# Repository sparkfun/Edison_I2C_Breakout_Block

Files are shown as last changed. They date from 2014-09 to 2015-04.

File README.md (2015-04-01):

SparkFun Edison I2C Breakout Block
==================================

SparkFun Edison I2C Breakout Block

[*SparkFun Edison I2C Breakout Block(DEV-13034)*](https://www.sparkfun.com/products/13034)

This I2C Block simply breaks out an I2C bus on the Intel® Edison while level shifting it from 1.8V to your sensors voltage. This a simple board that can snap into your Edison and be used right away.

Repository Contents
-------------------
* **Hardware** - All Eagle diesgn files (.brd, .sch)
* **/Production** - Test bed files and production panel files

License Information
-------------------
The hardware is released under [Creative Commons ShareAlike 4.0 International](https://creativecommons.org/licenses/by-sa/4.0/).
The code is beerware; if you see me (or any other SparkFun employee) at the local, and you've found our code helpful, please buy us a round!

Distributed as-is; no warranty is given.

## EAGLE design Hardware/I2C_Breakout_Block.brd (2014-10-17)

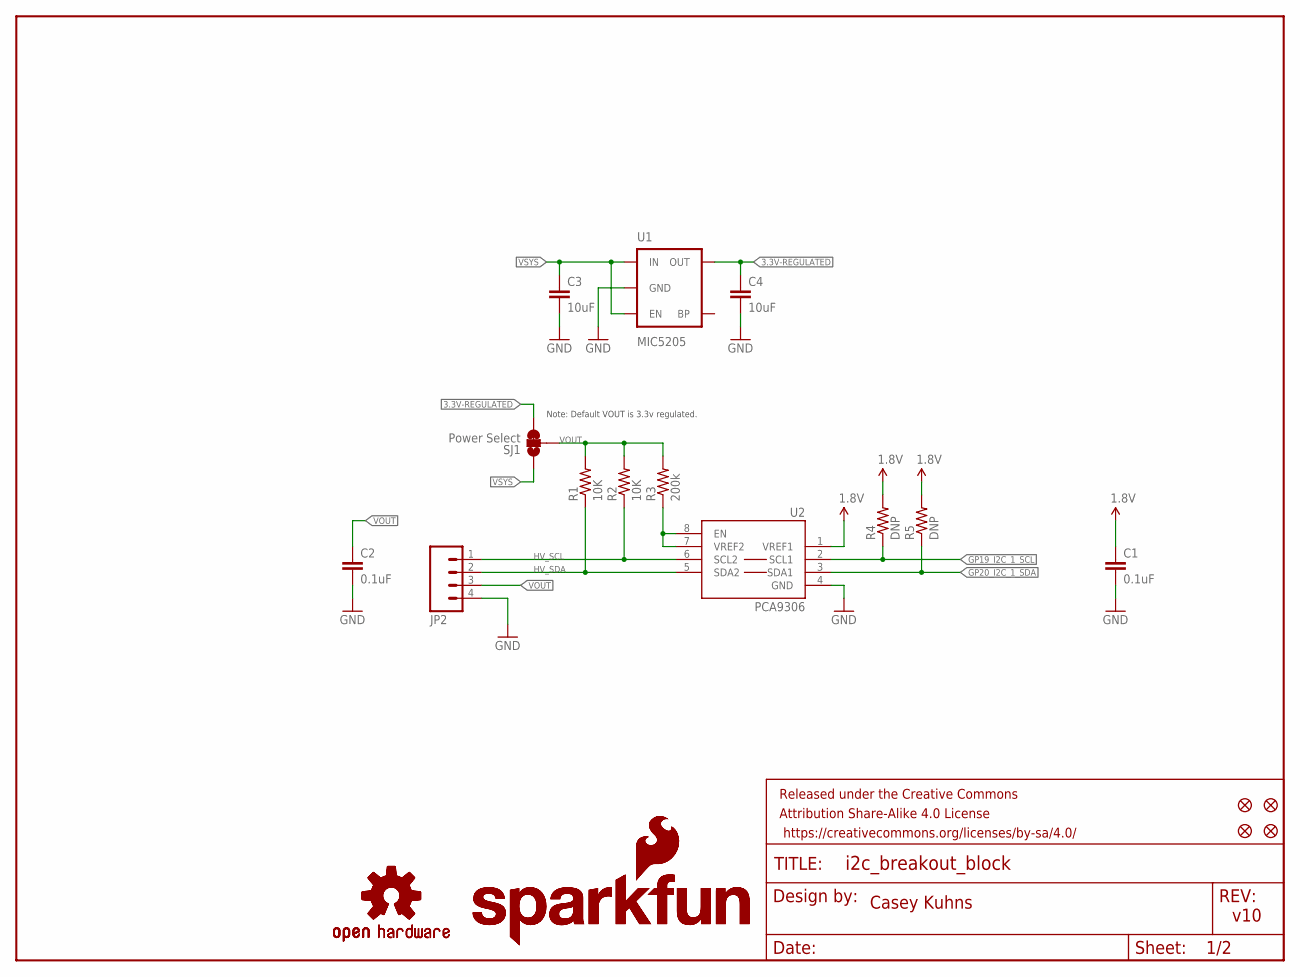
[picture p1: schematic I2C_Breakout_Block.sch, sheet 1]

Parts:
C1, C2: 0.1uF; 0603-CAP
C3, C4: 10uF; 1206
FID1, FID2, FID3, FID4: FIDUCIAL1X2; FIDUCIAL-1X2
FRAME1: FRAME-LETTER; CREATIVE_COMMONS
JP2: M04SMD_RA_FEMALE; 1X04_SMD_RA_FEMALE
LOGO1, LOGO3: SFE_LOGO_NAME_FLAME.1_INCH; SFE_LOGO_NAME_FLAME_.1
LOGO2, LOGO4: OSHW-LOGOS; OSHW-LOGO-S
R1, R2: 10K; 0603-RES
R3: 200k; 0603-RES
R4, R5: DNP; 0603-RES
SJ1: Power Select; PAD-JUMPER-3-2OF3_NC_BY_TRACE_YES_SILK_FULL_BOX
U1: MIC5205; SOT23-5
U2: PCA9306; PCA9306DC-1:1

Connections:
1.8V: C1.1, R4.2, R5.2, U2.1 (VREF1); also elsewhere on the board
3.3V-REGULATED: C4.1, SJ1.3, U1.5 (OUT)
GND: C1.2, C2.2, C3.2, C4.2, JP2.4, U1.2 (GND), U2.4 (GND); also elsewhere on the board
GP19_I2C_1_SCL: R4.1, U2.2 (SCL1); also elsewhere on the board
GP20_I2C_1_SDA: R5.1, U2.3 (SDA1); also elsewhere on the board
HV_SCL: JP2.1, R2.1, U2.6 (SCL2)
HV_SDA: JP2.2, R1.1, U2.5 (SDA2)
unnamed: R3.1, U2.7 (VREF2), U2.8 (EN)
VOUT: C2.1, JP2.3, R1.2, R2.2, R3.2, SJ1.2
VSYS: C3.1, SJ1.1, U1.1 (IN), U1.3 (EN); also elsewhere on the board

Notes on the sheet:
Casey Kuhns
v10
Note: Default VOUT is 3.3v regulated.

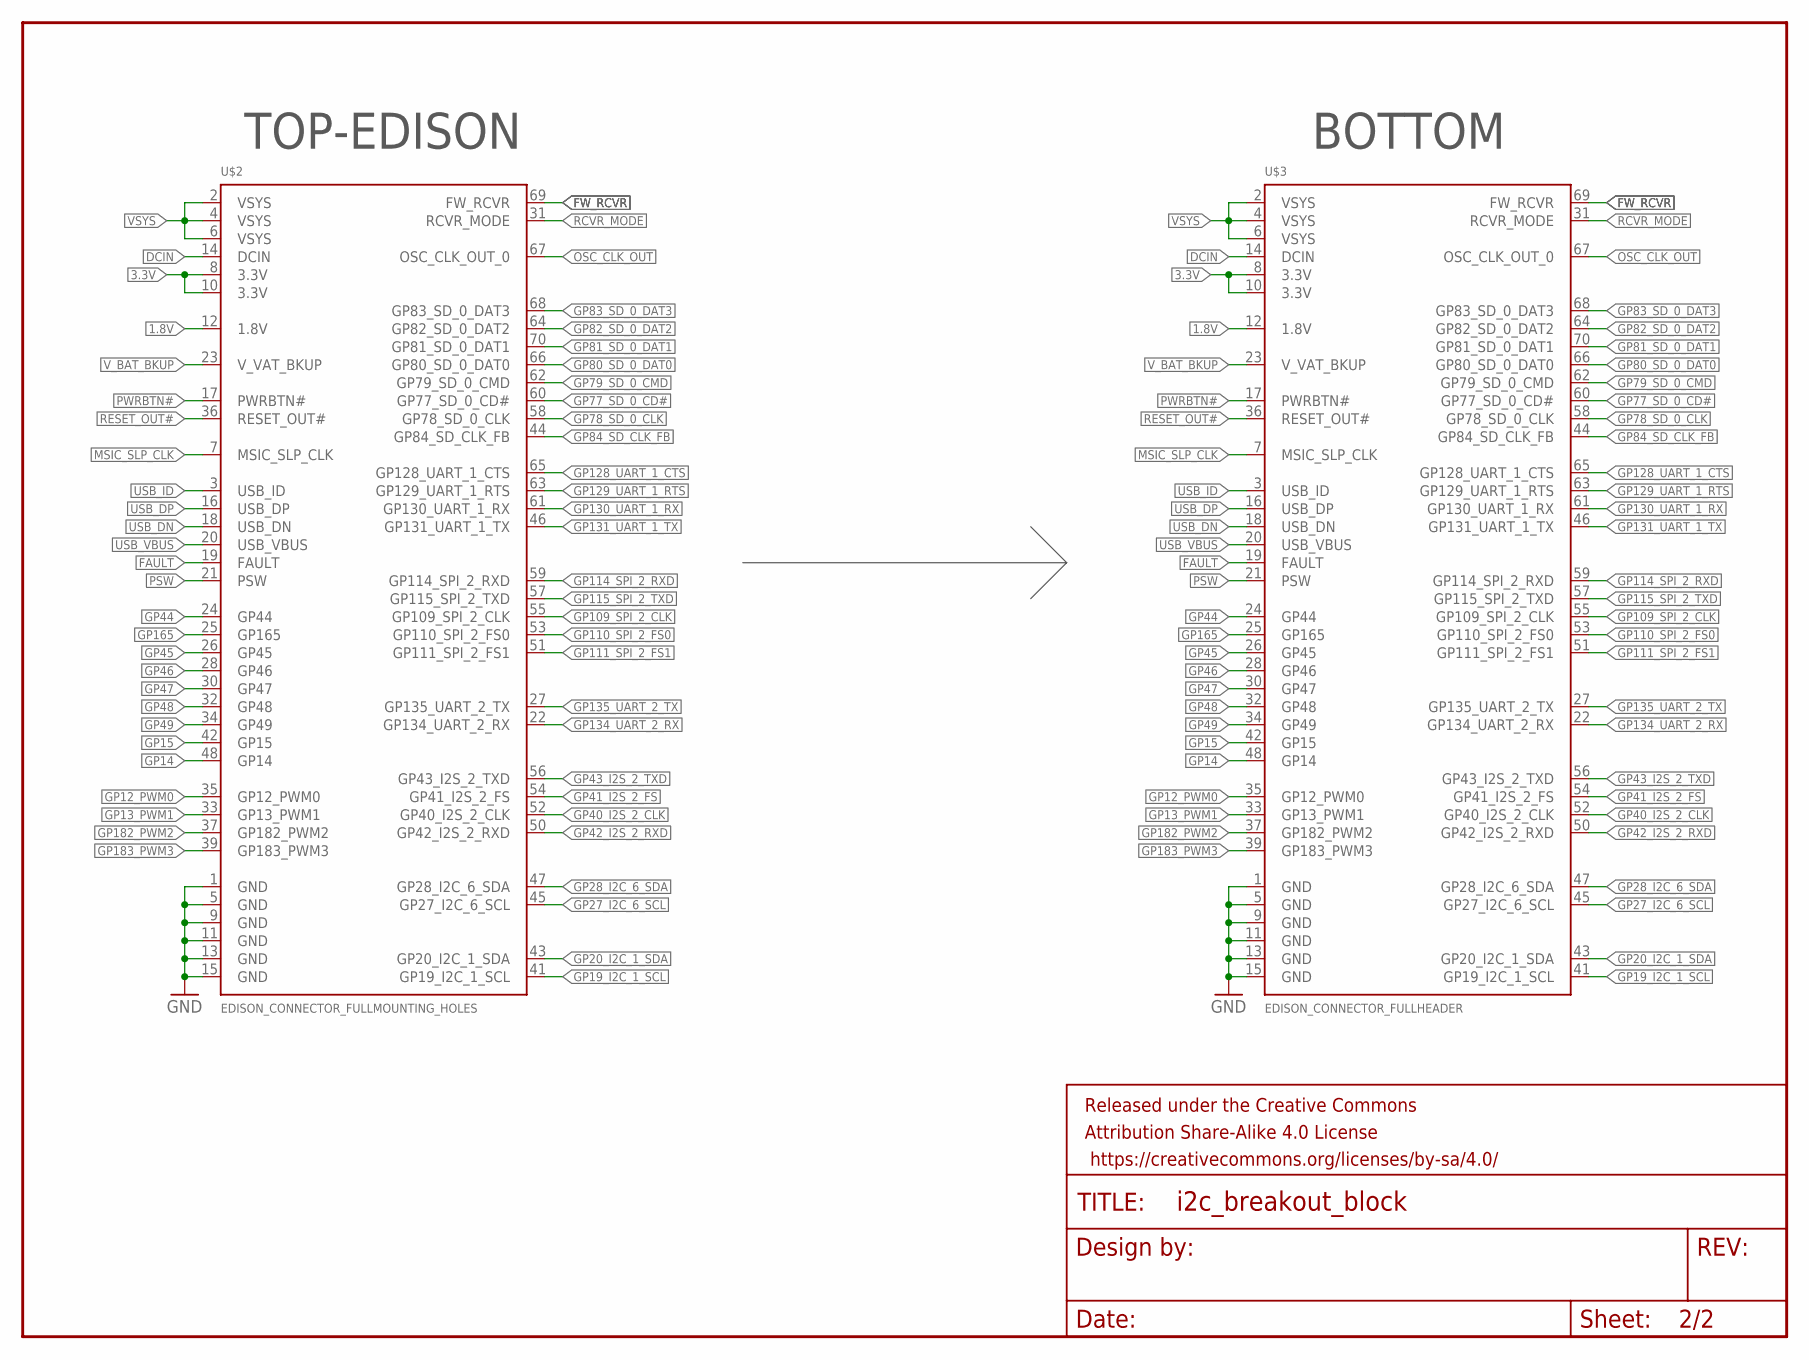
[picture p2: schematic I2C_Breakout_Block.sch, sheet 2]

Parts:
FRAME2: FRAME-LETTER; CREATIVE_COMMONS
U$2: EDISON_CONNECTOR_FULLMOUNTING_HOLES; EDISON_DAUGHTER
U$3: EDISON_CONNECTOR_FULLHEADER; DF40C-70DP-0.4(51)

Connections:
1.8V: U$2.12 (1.8V), U$3.12 (1.8V); also elsewhere on the board
3.3V: U$2.8 (3.3V), U$2.10 (3.3V), U$3.8 (3.3V), U$3.10 (3.3V)
DCIN: U$2.14 (DCIN), U$3.14 (DCIN)
FAULT: U$2.19 (FAULT), U$3.19 (FAULT)
FW_RCVR: U$2.69 (FW_RCVR), U$3.69 (FW_RCVR)
GND: U$2.1 (GND), U$2.5 (GND), U$2.9 (GND), U$2.11 (GND), U$2.13 (GND), U$2.15 (GND), U$3.1 (GND), U$3.5 (GND), U$3.9 (GND), U$3.11 (GND), U$3.13 (GND), U$3.15 (GND); also elsewhere on the board
GP12_PWM0: U$2.35 (GP12_PWM0), U$3.35 (GP12_PWM0)
GP13_PWM1: U$2.33 (GP13_PWM1), U$3.33 (GP13_PWM1)
GP14: U$2.48 (GP14), U$3.48 (GP14)
GP15: U$2.42 (GP15), U$3.42 (GP15)
GP19_I2C_1_SCL: U$2.41 (GP19_I2C_1_SCL), U$3.41 (GP19_I2C_1_SCL); also elsewhere on the board
GP20_I2C_1_SDA: U$2.43 (GP20_I2C_1_SDA), U$3.43 (GP20_I2C_1_SDA); also elsewhere on the board
GP27_I2C_6_SCL: U$2.45 (GP27_I2C_6_SCL), U$3.45 (GP27_I2C_6_SCL)
GP28_I2C_6_SDA: U$2.47 (GP28_I2C_6_SDA), U$3.47 (GP28_I2C_6_SDA)
GP40_I2S_2_CLK: U$2.52 (GP40_I2S_2_CLK), U$3.52 (GP40_I2S_2_CLK)
GP41_I2S_2_FS: U$2.54 (GP41_I2S_2_FS), U$3.54 (GP41_I2S_2_FS)
GP42_I2S_2_RXD: U$2.50 (GP42_I2S_2_RXD), U$3.50 (GP42_I2S_2_RXD)
GP43_I2S_2_TXD: U$2.56 (GP43_I2S_2_TXD), U$3.56 (GP43_I2S_2_TXD)
GP44: U$2.24 (GP44), U$3.24 (GP44)
GP45: U$2.26 (GP45), U$3.26 (GP45)
GP46: U$2.28 (GP46), U$3.28 (GP46)
GP47: U$2.30 (GP47), U$3.30 (GP47)
GP48: U$2.32 (GP48), U$3.32 (GP48)
GP49: U$2.34 (GP49), U$3.34 (GP49)
GP77_SD_0_CD#: U$2.60 (GP77_SD_0_CD#), U$3.60 (GP77_SD_0_CD#)
GP78_SD_0_CLK: U$2.58 (GP78_SD_0_CLK), U$3.58 (GP78_SD_0_CLK)
GP79_SD_0_CMD: U$2.62 (GP79_SD_0_CMD), U$3.62 (GP79_SD_0_CMD)
GP80_SD_0_DAT0: U$2.66 (GP80_SD_0_DAT0), U$3.66 (GP80_SD_0_DAT0)
GP81_SD_0_DAT1: U$2.70 (GP81_SD_0_DAT1), U$3.70 (GP81_SD_0_DAT1)
GP82_SD_0_DAT2: U$2.64 (GP82_SD_0_DAT2), U$3.64 (GP82_SD_0_DAT2)
GP83_SD_0_DAT3: U$2.68 (GP83_SD_0_DAT3), U$3.68 (GP83_SD_0_DAT3)
GP84_SD_CLK_FB: U$2.44 (GP84_SD_CLK_FB), U$3.44 (GP84_SD_CLK_FB)
GP109_SPI_2_CLK: U$2.55 (GP109_SPI_2_CLK), U$3.55 (GP109_SPI_2_CLK)
GP110_SPI_2_FS0: U$2.53 (GP110_SPI_2_FS0), U$3.53 (GP110_SPI_2_FS0)
GP111_SPI_2_FS1: U$2.51 (GP111_SPI_2_FS1), U$3.51 (GP111_SPI_2_FS1)
GP114_SPI_2_RXD: U$2.59 (GP114_SPI_2_RXD), U$3.59 (GP114_SPI_2_RXD)
GP115_SPI_2_TXD: U$2.57 (GP115_SPI_2_TXD), U$3.57 (GP115_SPI_2_TXD)
GP128_UART_1_CTS: U$2.65 (GP128_UART_1_CTS), U$3.65 (GP128_UART_1_CTS)
GP129_UART_1_RTS: U$2.63 (GP129_UART_1_RTS), U$3.63 (GP129_UART_1_RTS)
GP130_UART_1_RX: U$2.61 (GP130_UART_1_RX), U$3.61 (GP130_UART_1_RX)
GP131_UART_1_TX: U$2.46 (GP131_UART_1_TX), U$3.46 (GP131_UART_1_TX)
GP134_UART_2_RX: U$2.22 (GP134_UART_2_RX), U$3.22 (GP134_UART_2_RX)
GP135_UART_2_TX: U$2.27 (GP135_UART_2_TX), U$3.27 (GP135_UART_2_TX)
GP165: U$2.25 (GP165), U$3.25 (GP165)
GP182_PWM2: U$2.37 (GP182_PWM2), U$3.37 (GP182_PWM2)
GP183_PWM3: U$2.39 (GP183_PWM3), U$3.39 (GP183_PWM3)
MSIC_SLP_CLK: U$2.7 (MSIC_SLP_CLK), U$3.7 (MSIC_SLP_CLK)
OSC_CLK_OUT: U$2.67 (OSC_CLK_OUT_0), U$3.67 (OSC_CLK_OUT_0)
PSW: U$2.21 (PSW), U$3.21 (PSW)
PWRBTN#: U$2.17 (PWRBTN#), U$3.17 (PWRBTN#)
RCVR_MODE: U$2.31 (RCVR_MODE), U$3.31 (RCVR_MODE)
RESET_OUT#: U$2.36 (RESET_OUT#), U$3.36 (RESET_OUT#)
USB_DN: U$2.18 (USB_DN), U$3.18 (USB_DN)
USB_DP: U$2.16 (USB_DP), U$3.16 (USB_DP)
USB_ID: U$2.3 (USB_ID), U$3.3 (USB_ID)
USB_VBUS: U$2.20 (USB_VBUS), U$3.20 (USB_VBUS)
VSYS: U$2.2 (VSYS), U$2.4 (VSYS), U$2.6 (VSYS), U$3.2 (VSYS), U$3.4 (VSYS), U$3.6 (VSYS); also elsewhere on the board
V_BAT_BKUP: U$2.23 (V_VAT_BKUP), U$3.23 (V_VAT_BKUP)

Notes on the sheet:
TOP-EDISON
BOTTOM

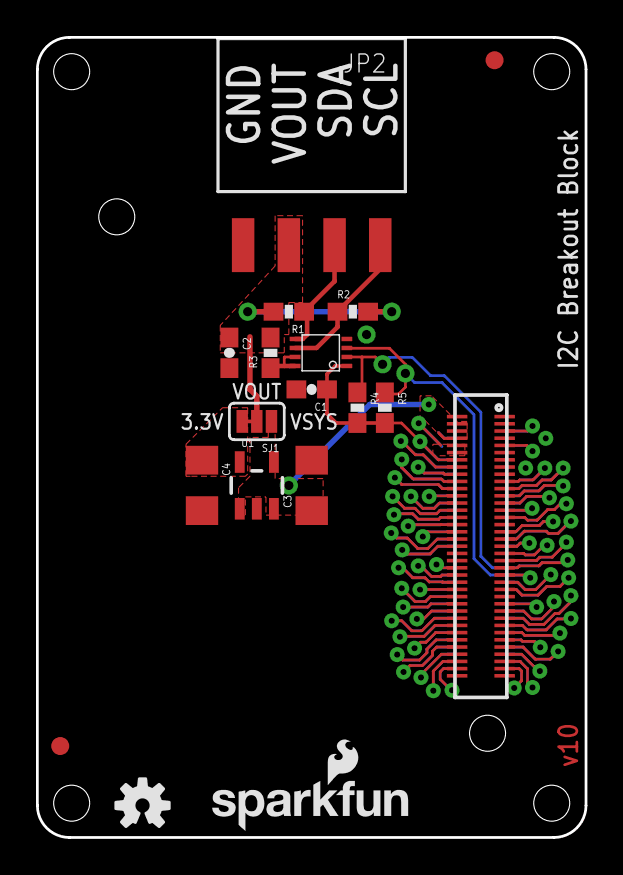
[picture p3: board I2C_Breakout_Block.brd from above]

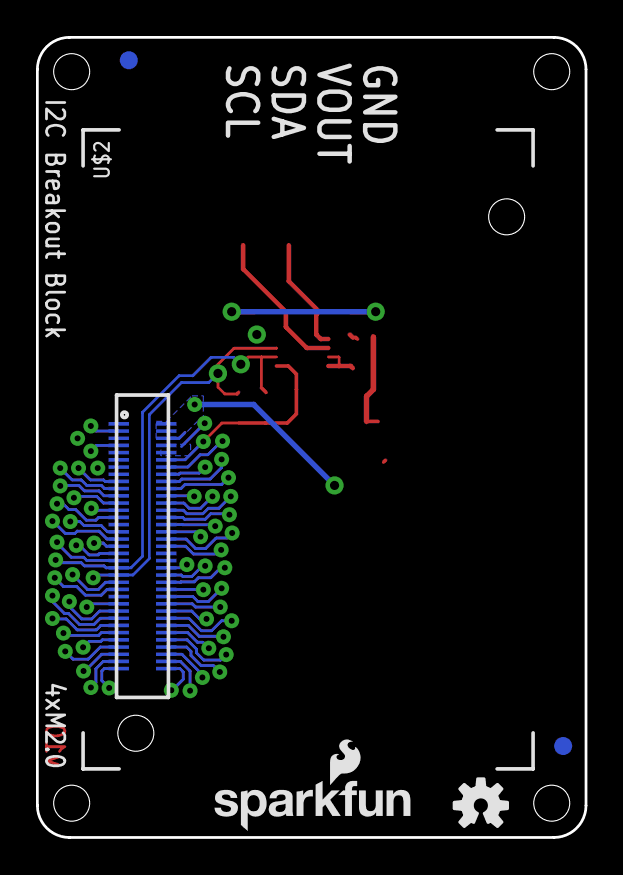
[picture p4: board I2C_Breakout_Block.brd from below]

Board: 2 copper layers, 30.5 x 44.5 mm, 25 parts (6 on the bottom side), 63 nets.

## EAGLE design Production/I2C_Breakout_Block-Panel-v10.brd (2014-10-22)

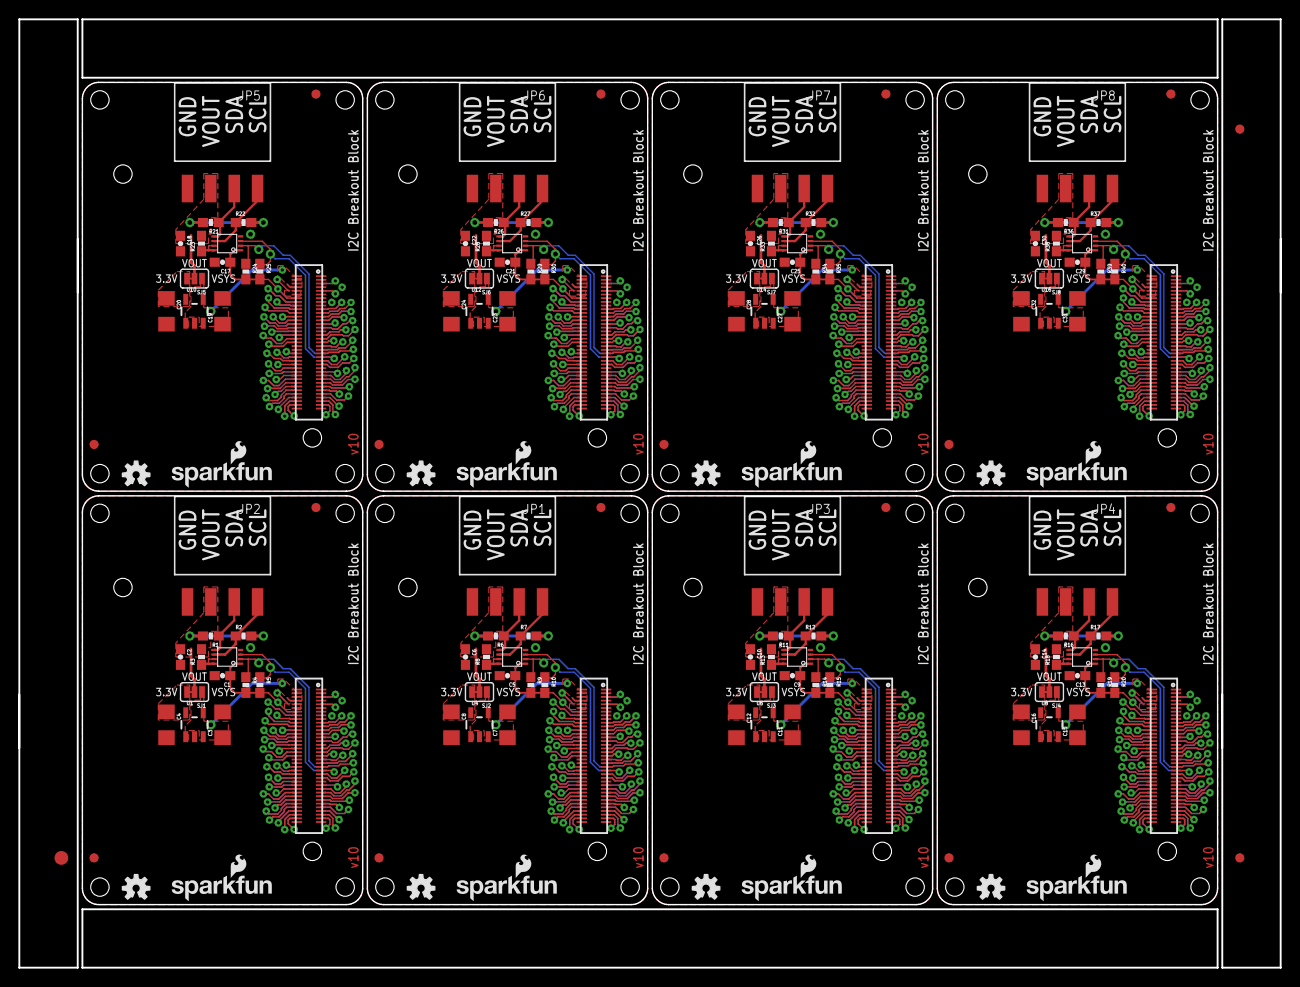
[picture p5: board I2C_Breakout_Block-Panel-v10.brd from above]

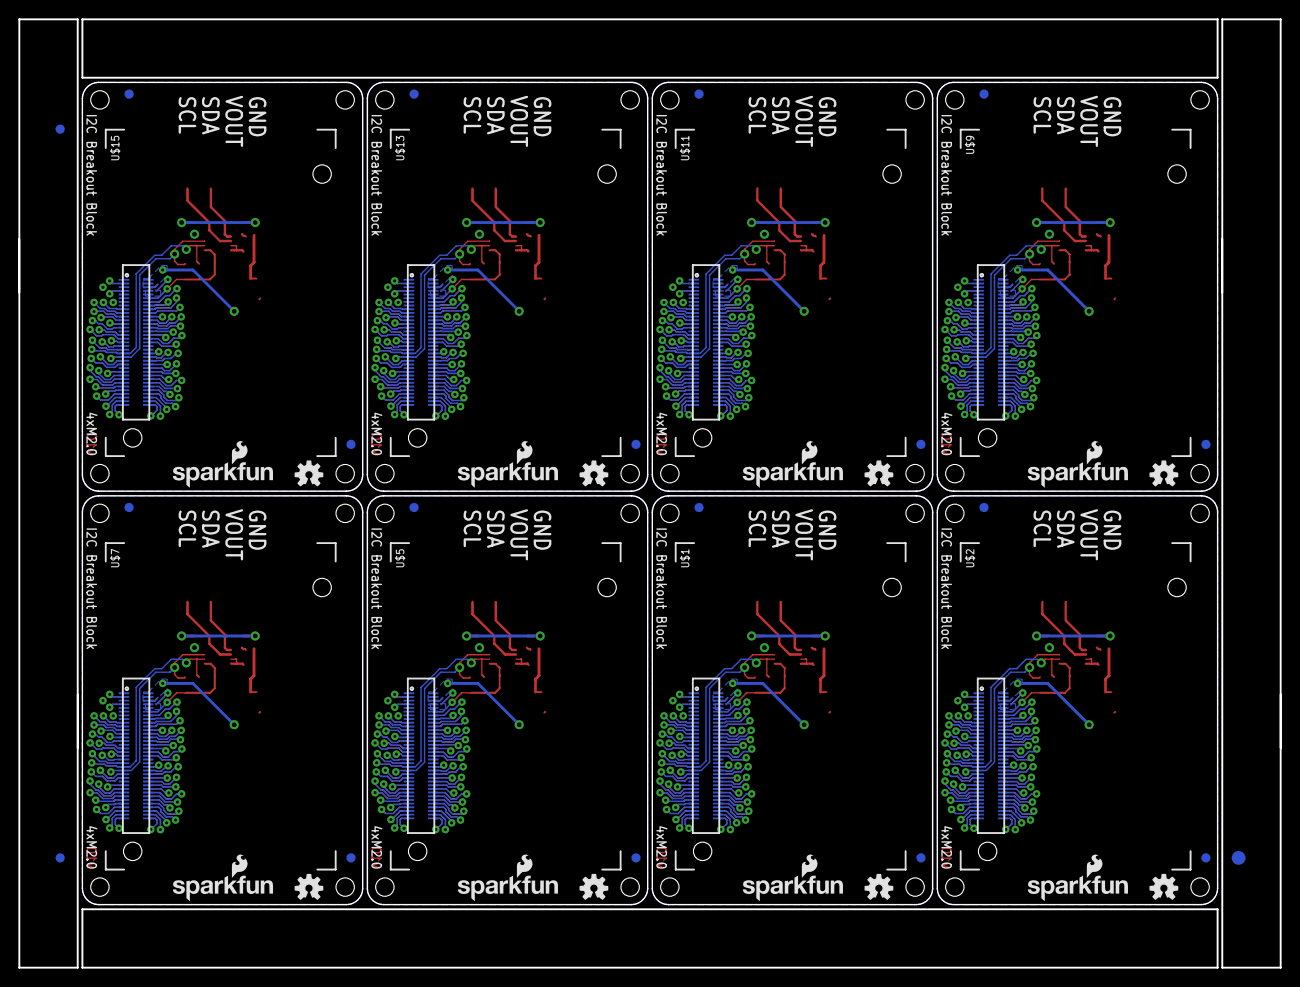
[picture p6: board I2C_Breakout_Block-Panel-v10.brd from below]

Board: 2 copper layers, 137.2 x 103.1 mm, 190 parts (51 on the bottom side), 504 nets.

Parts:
C1, C2, C5, C6, C9, C10, C13, C14, C17, C18, C21, C22, C25, C26, C29, C30: 0.1uF; 0603-CAP
C3, C4, C7, C8, C11, C12, C15, C16, C19, C20, C23, C24, C27, C28, C31, C32: 10uF; 1206
E$1, E$2: FIDUCIAL-1.5X3
E$3, E$4, E$5, E$6: FIDUCIAL-1X2
FID1, FID2, FID3, FID4, FID5, FID6, FID7, FID8, FID9, FID10, FID11, FID12, FID13, FID14, FID15, FID16, FID17, FID18, FID19, FID20, FID21, FID22, FID23, FID24, FID25, FID26, FID27, FID28, FID29, FID30, FID31, FID32: FIDUCIAL1X2; FIDUCIAL-1X2
JP1, JP2, JP3, JP4, JP5, JP6, JP7, JP8: 1X04_SMD_RA_FEMALE
LOGO1, LOGO3, LOGO6, LOGO7, LOGO10, LOGO11, LOGO14, LOGO15, LOGO18, LOGO19, LOGO22, LOGO23, LOGO26, LOGO27, LOGO30, LOGO31: SFE_LOGO_NAME_FLAME.1_INCH; SFE_LOGO_NAME_FLAME_.1
LOGO2, LOGO4, LOGO5, LOGO8, LOGO9, LOGO12, LOGO13, LOGO16, LOGO17, LOGO20, LOGO21, LOGO24, LOGO25, LOGO28, LOGO29, LOGO32: OSHW-LOGOS; OSHW-LOGO-S
R1, R2, R6, R7, R11, R12, R16, R17, R21, R22, R26, R27, R31, R32, R36, R37: 10K; 0603-RES
R3, R8, R13, R18, R23, R28, R33, R38: 200k; 0603-RES
R4, R5, R9, R10, R14, R15, R19, R20, R24, R25, R29, R30, R34, R35, R39, R40: DNP; 0603-RES
SJ1, SJ2, SJ3, SJ4, SJ5, SJ6, SJ7, SJ8: Power Select; PAD-JUMPER-3-2OF3_NC_BY_TRACE_YES_SILK_FULL_BOX
U1, U4, U6, U8, U10, U12, U14, U16: MIC5205; SOT23-5
U2, U3, U5, U7, U9, U11, U13, U15: PCA9306; PCA9306DC-1:1
U$1, U$2, U$5, U$7, U$9, U$11, U$13, U$15: EDISON_CONNECTOR_FULLMOUNTING_HOLES; EDISON_DAUGHTER
U$3, U$4, U$6, U$8, U$10, U$12, U$14, U$16: EDISON_CONNECTOR_FULLHEADER; DF40C-70DP-0.4(51)

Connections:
1.8V: C1.1, R4.2, R5.2, U2.1, U$2.12, U$3.12
1.8V1: C5.1, R9.2, R10.2, U3.1, U$1.12, U$4.12
1.8V2: C9.1, R14.2, R15.2, U5.1, U$5.12, U$6.12
1.8V3: C13.1, R19.2, R20.2, U7.1, U$7.12, U$8.12
1.8V4: C17.1, R24.2, R25.2, U9.1, U$9.12, U$10.12
1.8V5: C21.1, R29.2, R30.2, U11.1, U$11.12, U$12.12
1.8V6: C25.1, R34.2, R35.2, U13.1, U$13.12, U$14.12
1.8V7: C29.1, R39.2, R40.2, U15.1, U$15.12, U$16.12
3.3V: U$2.8, U$2.10, U$3.8, U$3.10
3.3V1: U$1.8, U$1.10, U$4.8, U$4.10
3.3V2: U$5.8, U$5.10, U$6.8, U$6.10
3.3V3: U$7.8, U$7.10, U$8.8, U$8.10
3.3V4: U$9.8, U$9.10, U$10.8, U$10.10
3.3V5: U$11.8, U$11.10, U$12.8, U$12.10
3.3V6: U$13.8, U$13.10, U$14.8, U$14.10
3.3V7: U$15.8, U$15.10, U$16.8, U$16.10
3.3V-REGULATED: C4.1, SJ1.3, U1.5
3.3V-REGULATED1: C8.1, SJ2.3, U4.5
3.3V-REGULATED2: C12.1, SJ3.3, U6.5
3.3V-REGULATED3: C16.1, SJ4.3, U8.5
3.3V-REGULATED4: C20.1, SJ5.3, U10.5
3.3V-REGULATED5: C24.1, SJ6.3, U12.5
3.3V-REGULATED6: C28.1, SJ7.3, U14.5
3.3V-REGULATED7: C32.1, SJ8.3, U16.5
DCIN: U$2.14, U$3.14
DCIN1: U$1.14, U$4.14
DCIN2: U$5.14, U$6.14
DCIN3: U$7.14, U$8.14
DCIN4: U$9.14, U$10.14
DCIN5: U$11.14, U$12.14
DCIN6: U$13.14, U$14.14
DCIN7: U$15.14, U$16.14
FAULT: U$2.19, U$3.19
FAULT1: U$1.19, U$4.19
FAULT2: U$5.19, U$6.19
FAULT3: U$7.19, U$8.19
FAULT4: U$9.19, U$10.19
FAULT5: U$11.19, U$12.19
FAULT6: U$13.19, U$14.19
FAULT7: U$15.19, U$16.19
FW_RCVR: U$2.69, U$3.69
FW_RCVR1: U$1.69, U$4.69
FW_RCVR2: U$5.69, U$6.69
FW_RCVR3: U$7.69, U$8.69
FW_RCVR4: U$9.69, U$10.69
FW_RCVR5: U$11.69, U$12.69
FW_RCVR6: U$13.69, U$14.69
FW_RCVR7: U$15.69, U$16.69
GND: C1.2, C2.2, C3.2, C4.2, JP2.4, U1.2, U2.4, U$2.1, U$2.5, U$2.9, U$2.11, U$2.13, U$2.15, U$3.1, U$3.5, U$3.9, U$3.11, U$3.13, U$3.15
GND1: C5.2, C6.2, C7.2, C8.2, JP1.4, U3.4, U4.2, U$1.1, U$1.5, U$1.9, U$1.11, U$1.13, U$1.15, U$4.1, U$4.5, U$4.9, U$4.11, U$4.13, U$4.15
GND2: C9.2, C10.2, C11.2, C12.2, JP3.4, U5.4, U6.2, U$5.1, U$5.5, U$5.9, U$5.11, U$5.13, U$5.15, U$6.1, U$6.5, U$6.9, U$6.11, U$6.13, U$6.15
GND3: C13.2, C14.2, C15.2, C16.2, JP4.4, U7.4, U8.2, U$7.1, U$7.5, U$7.9, U$7.11, U$7.13, U$7.15, U$8.1, U$8.5, U$8.9, U$8.11, U$8.13, U$8.15
GND4: C17.2, C18.2, C19.2, C20.2, JP5.4, U9.4, U10.2, U$9.1, U$9.5, U$9.9, U$9.11, U$9.13, U$9.15, U$10.1, U$10.5, U$10.9, U$10.11, U$10.13, U$10.15
GND5: C21.2, C22.2, C23.2, C24.2, JP6.4, U11.4, U12.2, U$11.1, U$11.5, U$11.9, U$11.11, U$11.13, U$11.15, U$12.1, U$12.5, U$12.9, U$12.11, U$12.13, U$12.15
GND6: C25.2, C26.2, C27.2, C28.2, JP7.4, U13.4, U14.2, U$13.1, U$13.5, U$13.9, U$13.11, U$13.13, U$13.15, U$14.1, U$14.5, U$14.9, U$14.11, U$14.13, U$14.15
GND7: C29.2, C30.2, C31.2, C32.2, JP8.4, U15.4, U16.2, U$15.1, U$15.5, U$15.9, U$15.11, U$15.13, U$15.15, U$16.1, U$16.5, U$16.9, U$16.11, U$16.13, U$16.15
GP1: U$1.48, U$4.48
GP2: U$1.42, U$4.42
GP3: U$1.34, U$4.34
GP4: U$1.32, U$4.32
GP5: U$1.30, U$4.30
GP6: U$1.28, U$4.28
GP7: U$1.26, U$4.26
GP8: U$1.25, U$4.25
GP9: U$1.24, U$4.24
GP10: U$5.48, U$6.48
GP11: U$5.42, U$6.42
GP12: U$5.34, U$6.34
GP12_PWM0: U$2.35, U$3.35
GP12_PWM1: U$1.35, U$4.35
GP12_PWM2: U$5.35, U$6.35
GP12_PWM3: U$7.35, U$8.35
GP12_PWM4: U$9.35, U$10.35
GP12_PWM5: U$11.35, U$12.35
GP12_PWM6: U$13.35, U$14.35
GP12_PWM7: U$15.35, U$16.35
GP13: U$5.32, U$6.32
GP13_PWM1: U$2.33, U$3.33
GP13_PWM2: U$1.33, U$4.33
GP13_PWM3: U$5.33, U$6.33
GP13_PWM4: U$7.33, U$8.33
GP13_PWM5: U$9.33, U$10.33
GP13_PWM6: U$11.33, U$12.33
GP13_PWM7: U$13.33, U$14.33
GP13_PWM8: U$15.33, U$16.33
GP14: U$2.48, U$3.48
GP15: U$2.42, U$3.42
GP16: U$5.30, U$6.30
GP17: U$5.28, U$6.28
GP18: U$5.26, U$6.26
GP19: U$5.25, U$6.25
GP19_I2C_1_SCL: R4.1, U2.2, U$2.41, U$3.41
GP19_I2C_1_SCL1: R9.1, U3.2, U$1.41, U$4.41
GP19_I2C_1_SCL2: R14.1, U5.2, U$5.41, U$6.41
GP19_I2C_1_SCL3: R19.1, U7.2, U$7.41, U$8.41
GP19_I2C_1_SCL4: R24.1, U9.2, U$9.41, U$10.41
GP19_I2C_1_SCL5: R29.1, U11.2, U$11.41, U$12.41
GP19_I2C_1_SCL6: R34.1, U13.2, U$13.41, U$14.41
GP19_I2C_1_SCL7: R39.1, U15.2, U$15.41, U$16.41
GP20: U$5.24, U$6.24
GP20_I2C_1_SDA: R5.1, U2.3, U$2.43, U$3.43
GP20_I2C_1_SDA1: R10.1, U3.3, U$1.43, U$4.43
GP20_I2C_1_SDA2: R15.1, U5.3, U$5.43, U$6.43
GP20_I2C_1_SDA3: R20.1, U7.3, U$7.43, U$8.43
GP20_I2C_1_SDA4: R25.1, U9.3, U$9.43, U$10.43
GP20_I2C_1_SDA5: R30.1, U11.3, U$11.43, U$12.43
GP20_I2C_1_SDA6: R35.1, U13.3, U$13.43, U$14.43
GP20_I2C_1_SDA7: R40.1, U15.3, U$15.43, U$16.43
GP21: U$7.48, U$8.48
GP22: U$7.42, U$8.42
GP23: U$7.34, U$8.34
GP24: U$7.32, U$8.32
GP25: U$7.30, U$8.30
GP26: U$7.28, U$8.28
GP27: U$7.26, U$8.26
GP27_I2C_6_SCL: U$2.45, U$3.45
GP27_I2C_6_SCL1: U$1.45, U$4.45
GP27_I2C_6_SCL2: U$5.45, U$6.45
GP27_I2C_6_SCL3: U$7.45, U$8.45
GP27_I2C_6_SCL4: U$9.45, U$10.45
GP27_I2C_6_SCL5: U$11.45, U$12.45
GP27_I2C_6_SCL6: U$13.45, U$14.45
GP27_I2C_6_SCL7: U$15.45, U$16.45
GP28: U$7.25, U$8.25
GP28_I2C_6_SDA: U$2.47, U$3.47
GP28_I2C_6_SDA1: U$1.47, U$4.47
GP28_I2C_6_SDA2: U$5.47, U$6.47
GP28_I2C_6_SDA3: U$7.47, U$8.47
GP28_I2C_6_SDA4: U$9.47, U$10.47
GP28_I2C_6_SDA5: U$11.47, U$12.47
GP28_I2C_6_SDA6: U$13.47, U$14.47
GP28_I2C_6_SDA7: U$15.47, U$16.47
GP29: U$7.24, U$8.24
GP30: U$9.48, U$10.48
GP31: U$9.42, U$10.42
GP32: U$9.34, U$10.34
GP33: U$9.32, U$10.32
GP34: U$9.30, U$10.30
GP35: U$9.28, U$10.28
GP36: U$9.26, U$10.26
GP37: U$9.25, U$10.25
GP38: U$9.24, U$10.24
GP39: U$11.48, U$12.48
GP40: U$11.42, U$12.42
GP40_I2S_2_CLK: U$2.52, U$3.52
GP40_I2S_2_CLK1: U$1.52, U$4.52
GP40_I2S_2_CLK2: U$5.52, U$6.52
GP40_I2S_2_CLK3: U$7.52, U$8.52
GP40_I2S_2_CLK4: U$9.52, U$10.52
GP40_I2S_2_CLK5: U$11.52, U$12.52
GP40_I2S_2_CLK6: U$13.52, U$14.52
GP40_I2S_2_CLK7: U$15.52, U$16.52
GP41: U$11.34, U$12.34
GP41_I2S_2_FS: U$2.54, U$3.54
GP41_I2S_2_FS1: U$1.54, U$4.54
GP41_I2S_2_FS2: U$5.54, U$6.54
GP41_I2S_2_FS3: U$7.54, U$8.54
GP41_I2S_2_FS4: U$9.54, U$10.54
GP41_I2S_2_FS5: U$11.54, U$12.54
GP41_I2S_2_FS6: U$13.54, U$14.54
GP41_I2S_2_FS7: U$15.54, U$16.54
GP42: U$11.32, U$12.32
GP42_I2S_2_RXD: U$2.50, U$3.50
GP42_I2S_2_RXD1: U$1.50, U$4.50
GP42_I2S_2_RXD2: U$5.50, U$6.50
GP42_I2S_2_RXD3: U$7.50, U$8.50
GP42_I2S_2_RXD4: U$9.50, U$10.50
GP42_I2S_2_RXD5: U$11.50, U$12.50
GP42_I2S_2_RXD6: U$13.50, U$14.50
GP42_I2S_2_RXD7: U$15.50, U$16.50
GP43: U$11.30, U$12.30
GP43_I2S_2_TXD: U$2.56, U$3.56
GP43_I2S_2_TXD1: U$1.56, U$4.56
GP43_I2S_2_TXD2: U$5.56, U$6.56
GP43_I2S_2_TXD3: U$7.56, U$8.56
GP43_I2S_2_TXD4: U$9.56, U$10.56
GP43_I2S_2_TXD5: U$11.56, U$12.56
GP43_I2S_2_TXD6: U$13.56, U$14.56
GP43_I2S_2_TXD7: U$15.56, U$16.56
GP44: U$2.24, U$3.24
GP45: U$2.26, U$3.26
GP46: U$2.28, U$3.28
GP47: U$2.30, U$3.30
GP48: U$2.32, U$3.32
GP49: U$2.34, U$3.34
GP50: U$11.28, U$12.28
GP51: U$11.26, U$12.26
GP52: U$11.25, U$12.25
GP53: U$11.24, U$12.24
GP54: U$13.48, U$14.48
GP55: U$13.42, U$14.42
GP56: U$13.34, U$14.34
GP57: U$13.32, U$14.32
GP58: U$13.30, U$14.30
GP59: U$13.28, U$14.28
GP60: U$13.26, U$14.26
GP61: U$13.25, U$14.25
GP62: U$13.24, U$14.24
GP63: U$15.48, U$16.48
GP64: U$15.42, U$16.42
GP65: U$15.34, U$16.34
GP66: U$15.32, U$16.32
GP67: U$15.30, U$16.30
GP68: U$15.28, U$16.28
GP69: U$15.26, U$16.26
GP70: U$15.25, U$16.25
GP71: U$15.24, U$16.24
GP77_SD_0_CD#: U$2.60, U$3.60
GP77_SD_0_CD#1: U$1.60, U$4.60
GP77_SD_0_CD#2: U$5.60, U$6.60
GP77_SD_0_CD#3: U$7.60, U$8.60
GP77_SD_0_CD#4: U$9.60, U$10.60
GP77_SD_0_CD#5: U$11.60, U$12.60
GP77_SD_0_CD#6: U$13.60, U$14.60
GP77_SD_0_CD#7: U$15.60, U$16.60
GP78_SD_0_CLK: U$2.58, U$3.58
GP78_SD_0_CLK1: U$1.58, U$4.58
GP78_SD_0_CLK2: U$5.58, U$6.58
GP78_SD_0_CLK3: U$7.58, U$8.58
GP78_SD_0_CLK4: U$9.58, U$10.58
GP78_SD_0_CLK5: U$11.58, U$12.58
GP78_SD_0_CLK6: U$13.58, U$14.58
GP78_SD_0_CLK7: U$15.58, U$16.58
GP79_SD_0_CMD: U$2.62, U$3.62
GP79_SD_0_CMD1: U$1.62, U$4.62
GP79_SD_0_CMD2: U$5.62, U$6.62
GP79_SD_0_CMD3: U$7.62, U$8.62
GP79_SD_0_CMD4: U$9.62, U$10.62
GP79_SD_0_CMD5: U$11.62, U$12.62
GP79_SD_0_CMD6: U$13.62, U$14.62
GP79_SD_0_CMD7: U$15.62, U$16.62
GP80_SD_0_DAT0: U$2.66, U$3.66
GP80_SD_0_DAT1: U$1.66, U$4.66
GP80_SD_0_DAT2: U$5.66, U$6.66
GP80_SD_0_DAT3: U$7.66, U$8.66
GP80_SD_0_DAT4: U$9.66, U$10.66
GP80_SD_0_DAT5: U$11.66, U$12.66
GP80_SD_0_DAT6: U$13.66, U$14.66
GP80_SD_0_DAT7: U$15.66, U$16.66
GP81_SD_0_DAT1: U$2.70, U$3.70
GP81_SD_0_DAT2: U$1.70, U$4.70
GP81_SD_0_DAT3: U$5.70, U$6.70
GP81_SD_0_DAT4: U$7.70, U$8.70
GP81_SD_0_DAT5: U$9.70, U$10.70
GP81_SD_0_DAT6: U$11.70, U$12.70
GP81_SD_0_DAT7: U$13.70, U$14.70
GP81_SD_0_DAT8: U$15.70, U$16.70
GP82_SD_0_DAT1: U$1.64, U$4.64
GP82_SD_0_DAT2: U$2.64, U$3.64
GP82_SD_0_DAT3: U$5.64, U$6.64
GP82_SD_0_DAT4: U$7.64, U$8.64
GP82_SD_0_DAT5: U$9.64, U$10.64
GP82_SD_0_DAT6: U$11.64, U$12.64
GP82_SD_0_DAT7: U$13.64, U$14.64
GP82_SD_0_DAT8: U$15.64, U$16.64
GP83_SD_0_DAT1: U$1.68, U$4.68
GP83_SD_0_DAT2: U$5.68, U$6.68
GP83_SD_0_DAT3: U$2.68, U$3.68
GP83_SD_0_DAT4: U$7.68, U$8.68
GP83_SD_0_DAT5: U$9.68, U$10.68
GP83_SD_0_DAT6: U$11.68, U$12.68
GP83_SD_0_DAT7: U$13.68, U$14.68
GP83_SD_0_DAT8: U$15.68, U$16.68
GP84_SD_CLK_FB: U$2.44, U$3.44
GP84_SD_CLK_FB1: U$1.44, U$4.44
GP84_SD_CLK_FB2: U$5.44, U$6.44
GP84_SD_CLK_FB3: U$7.44, U$8.44
GP84_SD_CLK_FB4: U$9.44, U$10.44
GP84_SD_CLK_FB5: U$11.44, U$12.44
GP84_SD_CLK_FB6: U$13.44, U$14.44
GP84_SD_CLK_FB7: U$15.44, U$16.44
GP109_SPI_2_CLK: U$2.55, U$3.55
GP109_SPI_2_CLK1: U$1.55, U$4.55
GP109_SPI_2_CLK2: U$5.55, U$6.55
GP109_SPI_2_CLK3: U$7.55, U$8.55
GP109_SPI_2_CLK4: U$9.55, U$10.55
GP109_SPI_2_CLK5: U$11.55, U$12.55
GP109_SPI_2_CLK6: U$13.55, U$14.55
GP109_SPI_2_CLK7: U$15.55, U$16.55
GP110_SPI_2_FS0: U$2.53, U$3.53
GP110_SPI_2_FS1: U$1.53, U$4.53
GP110_SPI_2_FS2: U$5.53, U$6.53
GP110_SPI_2_FS3: U$7.53, U$8.53
GP110_SPI_2_FS4: U$9.53, U$10.53
GP110_SPI_2_FS5: U$11.53, U$12.53
GP110_SPI_2_FS6: U$13.53, U$14.53
GP110_SPI_2_FS7: U$15.53, U$16.53
GP111_SPI_2_FS1: U$2.51, U$3.51
GP111_SPI_2_FS2: U$1.51, U$4.51
GP111_SPI_2_FS3: U$5.51, U$6.51
GP111_SPI_2_FS4: U$7.51, U$8.51
GP111_SPI_2_FS5: U$9.51, U$10.51
GP111_SPI_2_FS6: U$11.51, U$12.51
GP111_SPI_2_FS7: U$13.51, U$14.51
GP111_SPI_2_FS8: U$15.51, U$16.51
GP114_SPI_2_RXD: U$2.59, U$3.59
GP114_SPI_2_RXD1: U$1.59, U$4.59
GP114_SPI_2_RXD2: U$5.59, U$6.59
GP114_SPI_2_RXD3: U$7.59, U$8.59
GP114_SPI_2_RXD4: U$9.59, U$10.59
GP114_SPI_2_RXD5: U$11.59, U$12.59
GP114_SPI_2_RXD6: U$13.59, U$14.59
GP114_SPI_2_RXD7: U$15.59, U$16.59
GP115_SPI_2_TXD: U$2.57, U$3.57
GP115_SPI_2_TXD1: U$1.57, U$4.57
GP115_SPI_2_TXD2: U$5.57, U$6.57
GP115_SPI_2_TXD3: U$7.57, U$8.57
GP115_SPI_2_TXD4: U$9.57, U$10.57
GP115_SPI_2_TXD5: U$11.57, U$12.57
GP115_SPI_2_TXD6: U$13.57, U$14.57
GP115_SPI_2_TXD7: U$15.57, U$16.57
GP128_UART_1_CTS: U$2.65, U$3.65
GP128_UART_1_CTS1: U$1.65, U$4.65
GP128_UART_1_CTS2: U$5.65, U$6.65
GP128_UART_1_CTS3: U$7.65, U$8.65
GP128_UART_1_CTS4: U$9.65, U$10.65
GP128_UART_1_CTS5: U$11.65, U$12.65
GP128_UART_1_CTS6: U$13.65, U$14.65
GP128_UART_1_CTS7: U$15.65, U$16.65
GP129_UART_1_RTS: U$2.63, U$3.63
GP129_UART_1_RTS1: U$1.63, U$4.63
GP129_UART_1_RTS2: U$5.63, U$6.63
GP129_UART_1_RTS3: U$7.63, U$8.63
GP129_UART_1_RTS4: U$9.63, U$10.63
GP129_UART_1_RTS5: U$11.63, U$12.63
GP129_UART_1_RTS6: U$13.63, U$14.63
GP129_UART_1_RTS7: U$15.63, U$16.63
GP130_UART_1_RX: U$2.61, U$3.61
GP130_UART_1_RX1: U$1.61, U$4.61
GP130_UART_1_RX2: U$5.61, U$6.61
GP130_UART_1_RX3: U$7.61, U$8.61
GP130_UART_1_RX4: U$9.61, U$10.61
GP130_UART_1_RX5: U$11.61, U$12.61
GP130_UART_1_RX6: U$13.61, U$14.61
GP130_UART_1_RX7: U$15.61, U$16.61
GP131_UART_1_TX: U$2.46, U$3.46
GP131_UART_1_TX1: U$1.46, U$4.46
GP131_UART_1_TX2: U$5.46, U$6.46
GP131_UART_1_TX3: U$7.46, U$8.46
GP131_UART_1_TX4: U$9.46, U$10.46
GP131_UART_1_TX5: U$11.46, U$12.46
GP131_UART_1_TX6: U$13.46, U$14.46
GP131_UART_1_TX7: U$15.46, U$16.46
GP134_UART_2_RX: U$2.22, U$3.22
GP134_UART_2_RX1: U$1.22, U$4.22
GP134_UART_2_RX2: U$5.22, U$6.22
GP134_UART_2_RX3: U$7.22, U$8.22
GP134_UART_2_RX4: U$9.22, U$10.22
GP134_UART_2_RX5: U$11.22, U$12.22
GP134_UART_2_RX6: U$13.22, U$14.22
GP134_UART_2_RX7: U$15.22, U$16.22
GP135_UART_2_TX: U$2.27, U$3.27
GP135_UART_2_TX1: U$1.27, U$4.27
GP135_UART_2_TX2: U$5.27, U$6.27
GP135_UART_2_TX3: U$7.27, U$8.27
GP135_UART_2_TX4: U$9.27, U$10.27
GP135_UART_2_TX5: U$11.27, U$12.27
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

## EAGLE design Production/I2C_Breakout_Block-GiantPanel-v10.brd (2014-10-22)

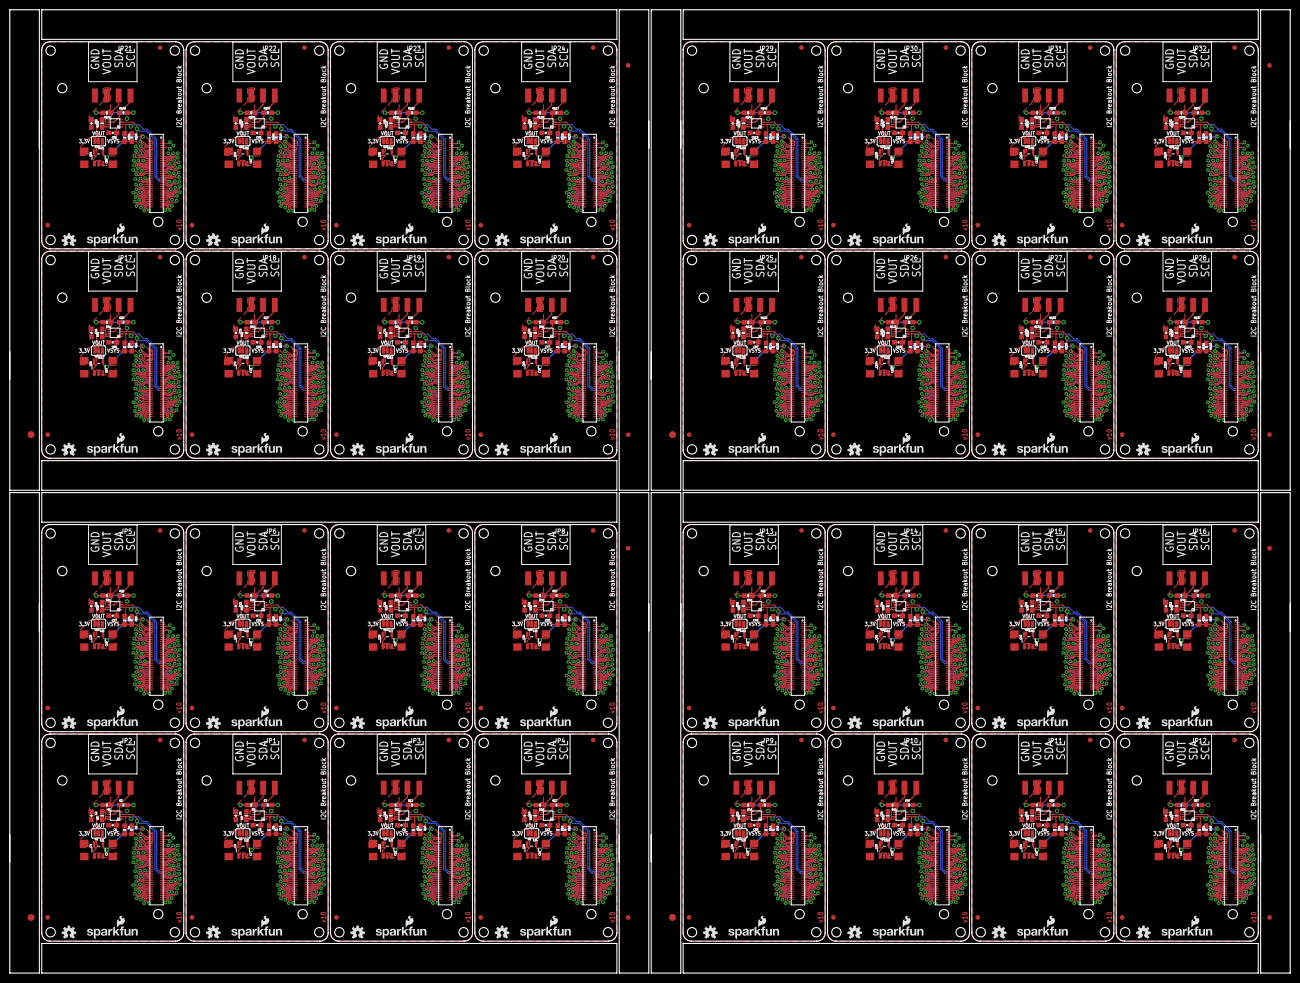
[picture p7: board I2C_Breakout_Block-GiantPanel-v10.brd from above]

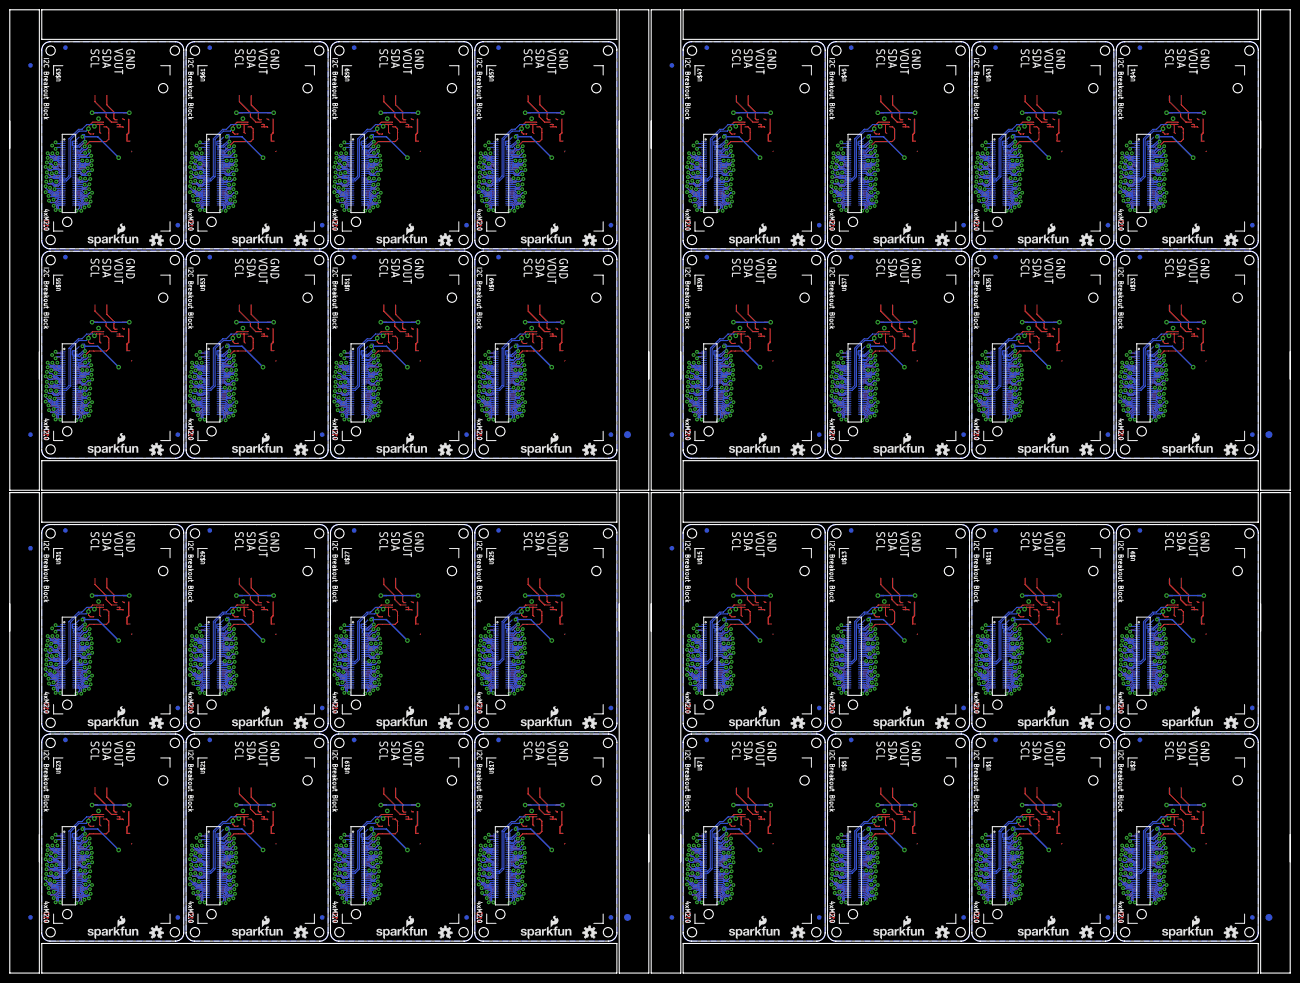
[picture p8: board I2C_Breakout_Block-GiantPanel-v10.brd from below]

Board: 2 copper layers, 274.8 x 206.8 mm, 760 parts (204 on the bottom side), 2016 nets.

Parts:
C1, C2, C5, C6, C9, C10, C13, C14, C17, C18, C21, C22, C25, C26, C29, C30, C33, C34, C37, C38, C41, C42, C45, C46, C49, C50, C53, C54, C57, C58, C61, C62, C65, C66, C69, C70, C73, C74, C77, C78, C81, C82, C85, C86, C89, C90, C93, C94, C97, C98, C101, C102, C105, C106, C109, C110, C113, C114, C117, C118, C121, C122, C125, C126: 0.1uF; 0603-CAP
C3, C4, C7, C8, C11, C12, C15, C16, C19, C20, C23, C24, C27, C28, C31, C32, C35, C36, C39, C40, C43, C44, C47, C48, C51, C52, C55, C56, C59, C60, C63, C64, C67, C68, C71, C72, C75, C76, C79, C80, C83, C84, C87, C88, C91, C92, C95, C96, C99, C100, C103, C104, C107, C108, C111, C112, C115, C116, C119, C120, C123, C124, C127, C128: 10uF; 1206
E$1, E$2, E$9, E$10, E$15, E$16, E$21, E$22: FIDUCIAL-1.5X3
E$3, E$4, E$5, E$6, E$7, E$8, E$11, E$12, E$13, E$14, E$17, E$18, E$19, E$20, E$23, E$24: FIDUCIAL-1X2
FID1, FID2, FID3, FID4, FID5, FID6, FID7, FID8, FID9, FID10, FID11, FID12, FID13, FID14, FID15, FID16, FID17, FID18, FID19, FID20, FID21, FID22, FID23, FID24, FID25, FID26, FID27, FID28, FID29, FID30, FID31, FID32, FID33, FID34, FID35, FID36, FID37, FID38, FID39, FID40, FID41, FID42, FID43, FID44, FID45, FID46, FID47, FID48, FID49, FID50, FID51, FID52, FID53, FID54, FID55, FID56, FID57, FID58, FID59, FID60, FID61, FID62, FID63, FID64, FID65, FID66, FID67, FID68, FID69, FID70, FID71, FID72, FID73, FID74, FID75, FID76, FID77, FID78, FID79, FID80, FID81, FID82, FID83, FID84, FID85, FID86, FID87, FID88, FID89, FID90, FID91, FID92, FID93, FID94, FID95, FID96, FID97, FID98, FID99, FID100, FID101, FID102, FID103, FID104, FID105, FID106, FID107, FID108, FID109, FID110, FID111, FID112, FID113, FID114, FID115, FID116, FID117, FID118, FID119, FID120, FID121, FID122, FID123, FID124, FID125, FID126, FID127, FID128: FIDUCIAL1X2; FIDUCIAL-1X2
JP1, JP2, JP3, JP4, JP5, JP6, JP7, JP8, JP9, JP10, JP11, JP12, JP13, JP14, JP15, JP16, JP17, JP18, JP19, JP20, JP21, JP22, JP23, JP24, JP25, JP26, JP27, JP28, JP29, JP30, JP31, JP32: 1X04_SMD_RA_FEMALE
LOGO1, LOGO3, LOGO6, LOGO7, LOGO10, LOGO11, LOGO14, LOGO15, LOGO18, LOGO19, LOGO22, LOGO23, LOGO26, LOGO27, LOGO30, LOGO31, LOGO34, LOGO35, LOGO38, LOGO39, LOGO42, LOGO43, LOGO46, LOGO47, LOGO50, LOGO51, LOGO54, LOGO55, LOGO58, LOGO59, LOGO62, LOGO63, LOGO66, LOGO67, LOGO70, LOGO71, LOGO74, LOGO75, LOGO78, LOGO79, LOGO82, LOGO83, LOGO86, LOGO87, LOGO90, LOGO91, LOGO94, LOGO95, LOGO98, LOGO99, LOGO102, LOGO103, LOGO106, LOGO107, LOGO110, LOGO111, LOGO114, LOGO115, LOGO118, LOGO119, LOGO122, LOGO123, LOGO126, LOGO127: SFE_LOGO_NAME_FLAME.1_INCH; SFE_LOGO_NAME_FLAME_.1
LOGO2, LOGO4, LOGO5, LOGO8, LOGO9, LOGO12, LOGO13, LOGO16, LOGO17, LOGO20, LOGO21, LOGO24, LOGO25, LOGO28, LOGO29, LOGO32, LOGO33, LOGO36, LOGO37, LOGO40, LOGO41, LOGO44, LOGO45, LOGO48, LOGO49, LOGO52, LOGO53, LOGO56, LOGO57, LOGO60, LOGO61, LOGO64, LOGO65, LOGO68, LOGO69, LOGO72, LOGO73, LOGO76, LOGO77, LOGO80, LOGO81, LOGO84, LOGO85, LOGO88, LOGO89, LOGO92, LOGO93, LOGO96, LOGO97, LOGO100, LOGO101, LOGO104, LOGO105, LOGO108, LOGO109, LOGO112, LOGO113, LOGO116, LOGO117, LOGO120, LOGO121, LOGO124, LOGO125, LOGO128: OSHW-LOGOS; OSHW-LOGO-S
R1, R2, R6, R7, R11, R12, R16, R17, R21, R22, R26, R27, R31, R32, R36, R37, R41, R42, R46, R47, R51, R52, R56, R57, R61, R62, R66, R67, R71, R72, R76, R77, R81, R82, R86, R87, R91, R92, R96, R97, R101, R102, R106, R107, R111, R112, R116, R117, R121, R122, R126, R127, R131, R132, R136, R137, R141, R142, R146, R147, R151, R152, R156, R157: 10K; 0603-RES
R3, R8, R13, R18, R23, R28, R33, R38, R43, R48, R53, R58, R63, R68, R73, R78, R83, R88, R93, R98, R103, R108, R113, R118, R123, R128, R133, R138, R143, R148, R153, R158: 200k; 0603-RES
R4, R5, R9, R10, R14, R15, R19, R20, R24, R25, R29, R30, R34, R35, R39, R40, R44, R45, R49, R50, R54, R55, R59, R60, R64, R65, R69, R70, R74, R75, R79, R80, R84, R85, R89, R90, R94, R95, R99, R100, R104, R105, R109, R110, R114, R115, R119, R120, R124, R125, R129, R130, R134, R135, R139, R140, R144, R145, R149, R150, R154, R155, R159, R160: DNP; 0603-RES
SJ1, SJ2, SJ3, SJ4, SJ5, SJ6, SJ7, SJ8, SJ9, SJ10, SJ11, SJ12, SJ13, SJ14, SJ15, SJ16, SJ17, SJ18, SJ19, SJ20, SJ21, SJ22, SJ23, SJ24, SJ25, SJ26, SJ27, SJ28, SJ29, SJ30, SJ31, SJ32: Power Select; PAD-JUMPER-3-2OF3_NC_BY_TRACE_YES_SILK_FULL_BOX
U1, U4, U6, U8, U10, U12, U14, U16, U18, U20, U22, U24, U26, U28, U30, U32, U34, U36, U38, U40, U42, U44, U46, U48, U50, U52, U54, U56, U58, U60, U62, U64: MIC5205; SOT23-5
U2, U3, U5, U7, U9, U11, U13, U15, U17, U19, U21, U23, U25, U27, U29, U31, U33, U35, U37, U39, U41, U43, U45, U47, U49, U51, U53, U55, U57, U59, U61, U63: PCA9306; PCA9306DC-1:1
U$1, U$2, U$5, U$7, U$9, U$11, U$13, U$15, U$17, U$19, U$21, U$23, U$25, U$27, U$29, U$31, U$33, U$35, U$37, U$39, U$41, U$43, U$45, U$47, U$49, U$51, U$53, U$55, U$57, U$59, U$61, U$63: EDISON_CONNECTOR_FULLMOUNTING_HOLES; EDISON_DAUGHTER
U$3, U$4, U$6, U$8, U$10, U$12, U$14, U$16, U$18, U$20, U$22, U$24, U$26, U$28, U$30, U$32, U$34, U$36, U$38, U$40, U$42, U$44, U$46, U$48, U$50, U$52, U$54, U$56, U$58, U$60, U$62, U$64: EDISON_CONNECTOR_FULLHEADER; DF40C-70DP-0.4(51)

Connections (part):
1.8V: C1.1, R4.2, R5.2, U2.1, U$2.12, U$3.12
1.8V1: C5.1, R9.2, R10.2, U3.1, U$1.12, U$4.12
1.8V2: C9.1, R14.2, R15.2, U5.1, U$5.12, U$6.12
1.8V3: C13.1, R19.2, R20.2, U7.1, U$7.12, U$8.12
1.8V4: C17.1, R24.2, R25.2, U9.1, U$9.12, U$10.12
1.8V5: C21.1, R29.2, R30.2, U11.1, U$11.12, U$12.12
1.8V6: C25.1, R34.2, R35.2, U13.1, U$13.12, U$14.12
1.8V7: C29.1, R39.2, R40.2, U15.1, U$15.12, U$16.12
1.8V8: C33.1, R44.2, R45.2, U17.1, U$17.12, U$18.12
1.8V9: C37.1, R49.2, R50.2, U19.1, U$19.12, U$20.12
1.8V10: C41.1, R54.2, R55.2, U21.1, U$21.12, U$22.12
1.8V11: C45.1, R59.2, R60.2, U23.1, U$23.12, U$24.12
1.8V12: C49.1, R64.2, R65.2, U25.1, U$25.12, U$26.12
1.8V13: C53.1, R69.2, R70.2, U27.1, U$27.12, U$28.12
1.8V14: C57.1, R74.2, R75.2, U29.1, U$29.12, U$30.12
1.8V15: C61.1, R79.2, R80.2, U31.1, U$31.12, U$32.12
1.8V16: C65.1, R84.2, R85.2, U33.1, U$33.12, U$34.12
1.8V17: C69.1, R89.2, R90.2, U35.1, U$35.12, U$36.12
1.8V18: C73.1, R94.2, R95.2, U37.1, U$37.12, U$38.12
1.8V19: C77.1, R99.2, R100.2, U39.1, U$39.12, U$40.12
1.8V20: C81.1, R104.2, R105.2, U41.1, U$41.12, U$42.12
1.8V21: C85.1, R109.2, R110.2, U43.1, U$43.12, U$44.12
1.8V22: C89.1, R114.2, R115.2, U45.1, U$45.12, U$46.12
1.8V23: C93.1, R119.2, R120.2, U47.1, U$47.12, U$48.12
1.8V24: C97.1, R124.2, R125.2, U49.1, U$49.12, U$50.12
1.8V25: C101.1, R129.2, R130.2, U51.1, U$51.12, U$52.12
1.8V26: C105.1, R134.2, R135.2, U53.1, U$53.12, U$54.12
1.8V27: C109.1, R139.2, R140.2, U55.1, U$55.12, U$56.12
1.8V28: C113.1, R144.2, R145.2, U57.1, U$57.12, U$58.12
1.8V29: C117.1, R149.2, R150.2, U59.1, U$59.12, U$60.12
1.8V30: C121.1, R154.2, R155.2, U61.1, U$61.12, U$62.12
1.8V31: C125.1, R159.2, R160.2, U63.1, U$63.12, U$64.12
3.3V: U$2.8, U$2.10, U$3.8, U$3.10
3.3V1: U$1.8, U$1.10, U$4.8, U$4.10
3.3V2: U$5.8, U$5.10, U$6.8, U$6.10
3.3V3: U$7.8, U$7.10, U$8.8, U$8.10
3.3V4: U$9.8, U$9.10, U$10.8, U$10.10
3.3V5: U$11.8, U$11.10, U$12.8, U$12.10
3.3V6: U$13.8, U$13.10, U$14.8, U$14.10
3.3V7: U$15.8, U$15.10, U$16.8, U$16.10
3.3V8: U$17.8, U$17.10, U$18.8, U$18.10
3.3V9: U$19.8, U$19.10, U$20.8, U$20.10
3.3V10: U$21.8, U$21.10, U$22.8, U$22.10
3.3V11: U$23.8, U$23.10, U$24.8, U$24.10
3.3V12: U$25.8, U$25.10, U$26.8, U$26.10
3.3V13: U$27.8, U$27.10, U$28.8, U$28.10
3.3V14: U$29.8, U$29.10, U$30.8, U$30.10
3.3V15: U$31.8, U$31.10, U$32.8, U$32.10
3.3V16: U$33.8, U$33.10, U$34.8, U$34.10
3.3V17: U$35.8, U$35.10, U$36.8, U$36.10
3.3V18: U$37.8, U$37.10, U$38.8, U$38.10
3.3V19: U$39.8, U$39.10, U$40.8, U$40.10
3.3V20: U$41.8, U$41.10, U$42.8, U$42.10
3.3V21: U$43.8, U$43.10, U$44.8, U$44.10
3.3V22: U$45.8, U$45.10, U$46.8, U$46.10
3.3V23: U$47.8, U$47.10, U$48.8, U$48.10
3.3V24: U$49.8, U$49.10, U$50.8, U$50.10
3.3V25: U$51.8, U$51.10, U$52.8, U$52.10
3.3V26: U$53.8, U$53.10, U$54.8, U$54.10
3.3V27: U$55.8, U$55.10, U$56.8, U$56.10
3.3V28: U$57.8, U$57.10, U$58.8, U$58.10
3.3V29: U$59.8, U$59.10, U$60.8, U$60.10
3.3V30: U$61.8, U$61.10, U$62.8, U$62.10
3.3V31: U$63.8, U$63.10, U$64.8, U$64.10
3.3V-REGULATED: C4.1, SJ1.3, U1.5
3.3V-REGULATED1: C8.1, SJ2.3, U4.5
3.3V-REGULATED2: C12.1, SJ3.3, U6.5
3.3V-REGULATED3: C16.1, SJ4.3, U8.5
3.3V-REGULATED4: C20.1, SJ5.3, U10.5
3.3V-REGULATED5: C24.1, SJ6.3, U12.5
3.3V-REGULATED6: C28.1, SJ7.3, U14.5
3.3V-REGULATED7: C32.1, SJ8.3, U16.5
3.3V-REGULATED8: C36.1, SJ9.3, U18.5
3.3V-REGULATED9: C40.1, SJ10.3, U20.5
3.3V-REGULATED10: C44.1, SJ11.3, U22.5
3.3V-REGULATED11: C48.1, SJ12.3, U24.5
3.3V-REGULATED12: C52.1, SJ13.3, U26.5
3.3V-REGULATED13: C56.1, SJ14.3, U28.5
3.3V-REGULATED14: C60.1, SJ15.3, U30.5
3.3V-REGULATED15: C64.1, SJ16.3, U32.5
3.3V-REGULATED16: C68.1, SJ17.3, U34.5
3.3V-REGULATED17: C72.1, SJ18.3, U36.5
3.3V-REGULATED18: C76.1, SJ19.3, U38.5
3.3V-REGULATED19: C80.1, SJ20.3, U40.5
3.3V-REGULATED20: C84.1, SJ21.3, U42.5
3.3V-REGULATED21: C88.1, SJ22.3, U44.5
3.3V-REGULATED22: C92.1, SJ23.3, U46.5
3.3V-REGULATED23: C96.1, SJ24.3, U48.5
3.3V-REGULATED24: C100.1, SJ25.3, U50.5
3.3V-REGULATED25: C104.1, SJ26.3, U52.5
3.3V-REGULATED26: C108.1, SJ27.3, U54.5
3.3V-REGULATED27: C112.1, SJ28.3, U56.5
3.3V-REGULATED28: C116.1, SJ29.3, U58.5
3.3V-REGULATED29: C120.1, SJ30.3, U60.5
3.3V-REGULATED30: C124.1, SJ31.3, U62.5
3.3V-REGULATED31: C128.1, SJ32.3, U64.5
DCIN: U$2.14, U$3.14
DCIN1: U$1.14, U$4.14
DCIN2: U$5.14, U$6.14
DCIN3: U$7.14, U$8.14
DCIN4: U$9.14, U$10.14
DCIN5: U$11.14, U$12.14
DCIN6: U$13.14, U$14.14
DCIN7: U$15.14, U$16.14
DCIN8: U$17.14, U$18.14
DCIN9: U$19.14, U$20.14
DCIN10: U$21.14, U$22.14
DCIN11: U$23.14, U$24.14
DCIN12: U$25.14, U$26.14
DCIN13: U$27.14, U$28.14
DCIN14: U$29.14, U$30.14
DCIN15: U$31.14, U$32.14
DCIN16: U$33.14, U$34.14
DCIN17: U$35.14, U$36.14
DCIN18: U$37.14, U$38.14
DCIN19: U$39.14, U$40.14
DCIN20: U$41.14, U$42.14
DCIN21: U$43.14, U$44.14
DCIN22: U$45.14, U$46.14
DCIN23: U$47.14, U$48.14
DCIN24: U$49.14, U$50.14
DCIN25: U$51.14, U$52.14
DCIN26: U$53.14, U$54.14
DCIN27: U$55.14, U$56.14
DCIN28: U$57.14, U$58.14
DCIN29: U$59.14, U$60.14
DCIN30: U$61.14, U$62.14
DCIN31: U$63.14, U$64.14
FAULT: U$2.19, U$3.19
FAULT1: U$1.19, U$4.19
FAULT2: U$5.19, U$6.19
FAULT3: U$7.19, U$8.19
FAULT4: U$9.19, U$10.19
FAULT5: U$11.19, U$12.19
FAULT6: U$13.19, U$14.19
FAULT7: U$15.19, U$16.19
FAULT8: U$17.19, U$18.19
FAULT9: U$19.19, U$20.19
FAULT10: U$21.19, U$22.19
FAULT11: U$23.19, U$24.19
FAULT12: U$25.19, U$26.19
FAULT13: U$27.19, U$28.19
FAULT14: U$29.19, U$30.19
FAULT15: U$31.19, U$32.19
FAULT16: U$33.19, U$34.19
FAULT17: U$35.19, U$36.19
FAULT18: U$37.19, U$38.19
FAULT19: U$39.19, U$40.19
FAULT20: U$41.19, U$42.19
FAULT21: U$43.19, U$44.19
FAULT22: U$45.19, U$46.19
FAULT23: U$47.19, U$48.19
FAULT24: U$49.19, U$50.19
FAULT25: U$51.19, U$52.19
FAULT26: U$53.19, U$54.19
FAULT27: U$55.19, U$56.19
FAULT28: U$57.19, U$58.19
FAULT29: U$59.19, U$60.19
FAULT30: U$61.19, U$62.19
FAULT31: U$63.19, U$64.19
FW_RCVR: U$2.69, U$3.69
FW_RCVR1: U$1.69, U$4.69
FW_RCVR2: U$5.69, U$6.69
FW_RCVR3: U$7.69, U$8.69
FW_RCVR4: U$9.69, U$10.69
FW_RCVR5: U$11.69, U$12.69
FW_RCVR6: U$13.69, U$14.69
FW_RCVR7: U$15.69, U$16.69
FW_RCVR8: U$17.69, U$18.69
FW_RCVR9: U$19.69, U$20.69
FW_RCVR10: U$21.69, U$22.69
FW_RCVR11: U$23.69, U$24.69
FW_RCVR12: U$25.69, U$26.69
FW_RCVR13: U$27.69, U$28.69
FW_RCVR14: U$29.69, U$30.69
FW_RCVR15: U$31.69, U$32.69
FW_RCVR16: U$33.69, U$34.69
FW_RCVR17: U$35.69, U$36.69
FW_RCVR18: U$37.69, U$38.69
FW_RCVR19: U$39.69, U$40.69
FW_RCVR20: U$41.69, U$42.69
FW_RCVR21: U$43.69, U$44.69
FW_RCVR22: U$45.69, U$46.69
FW_RCVR23: U$47.69, U$48.69
FW_RCVR24: U$49.69, U$50.69
FW_RCVR25: U$51.69, U$52.69
FW_RCVR26: U$53.69, U$54.69
FW_RCVR27: U$55.69, U$56.69
FW_RCVR28: U$57.69, U$58.69
FW_RCVR29: U$59.69, U$60.69
FW_RCVR30: U$61.69, U$62.69
FW_RCVR31: U$63.69, U$64.69
GND: C1.2, C2.2, C3.2, C4.2, JP2.4, U1.2, U2.4, U$2.1, U$2.5, U$2.9, U$2.11, U$2.13, U$2.15, U$3.1, U$3.5, U$3.9, U$3.11, U$3.13, U$3.15
GND1: C5.2, C6.2, C7.2, C8.2, JP1.4, U3.4, U4.2, U$1.1, U$1.5, U$1.9, U$1.11, U$1.13, U$1.15, U$4.1, U$4.5, U$4.9, U$4.11, U$4.13, U$4.15
GND2: C9.2, C10.2, C11.2, C12.2, JP3.4, U5.4, U6.2, U$5.1, U$5.5, U$5.9, U$5.11, U$5.13, U$5.15, U$6.1, U$6.5, U$6.9, U$6.11, U$6.13, U$6.15
GND3: C13.2, C14.2, C15.2, C16.2, JP4.4, U7.4, U8.2, U$7.1, U$7.5, U$7.9, U$7.11, U$7.13, U$7.15, U$8.1, U$8.5, U$8.9, U$8.11, U$8.13, U$8.15
GND4: C17.2, C18.2, C19.2, C20.2, JP5.4, U9.4, U10.2, U$9.1, U$9.5, U$9.9, U$9.11, U$9.13, U$9.15, U$10.1, U$10.5, U$10.9, U$10.11, U$10.13, U$10.15
GND5: C21.2, C22.2, C23.2, C24.2, JP6.4, U11.4, U12.2, U$11.1, U$11.5, U$11.9, U$11.11, U$11.13, U$11.15, U$12.1, U$12.5, U$12.9, U$12.11, U$12.13, U$12.15
GND6: C25.2, C26.2, C27.2, C28.2, JP7.4, U13.4, U14.2, U$13.1, U$13.5, U$13.9, U$13.11, U$13.13, U$13.15, U$14.1, U$14.5, U$14.9, U$14.11, U$14.13, U$14.15
GND7: C29.2, C30.2, C31.2, C32.2, JP8.4, U15.4, U16.2, U$15.1, U$15.5, U$15.9, U$15.11, U$15.13, U$15.15, U$16.1, U$16.5, U$16.9, U$16.11, U$16.13, U$16.15
GND8: C33.2, C34.2, C35.2, C36.2, JP9.4, U17.4, U18.2, U$17.1, U$17.5, U$17.9, U$17.11, U$17.13, U$17.15, U$18.1, U$18.5, U$18.9, U$18.11, U$18.13, U$18.15
GND9: C37.2, C38.2, C39.2, C40.2, JP10.4, U19.4, U20.2, U$19.1, U$19.5, U$19.9, U$19.11, U$19.13, U$19.15, U$20.1, U$20.5, U$20.9, U$20.11, U$20.13, U$20.15
GND10: C41.2, C42.2, C43.2, C44.2, JP11.4, U21.4, U22.2, U$21.1, U$21.5, U$21.9, U$21.11, U$21.13, U$21.15, U$22.1, U$22.5, U$22.9, U$22.11, U$22.13, U$22.15
GND11: C45.2, C46.2, C47.2, C48.2, JP12.4, U23.4, U24.2, U$23.1, U$23.5, U$23.9, U$23.11, U$23.13, U$23.15, U$24.1, U$24.5, U$24.9, U$24.11, U$24.13, U$24.15
GND12: C49.2, C50.2, C51.2, C52.2, JP13.4, U25.4, U26.2, U$25.1, U$25.5, U$25.9, U$25.11, U$25.13, U$25.15, U$26.1, U$26.5, U$26.9, U$26.11, U$26.13, U$26.15
GND13: C53.2, C54.2, C55.2, C56.2, JP14.4, U27.4, U28.2, U$27.1, U$27.5, U$27.9, U$27.11, U$27.13, U$27.15, U$28.1, U$28.5, U$28.9, U$28.11, U$28.13, U$28.15
GND14: C57.2, C58.2, C59.2, C60.2, JP15.4, U29.4, U30.2, U$29.1, U$29.5, U$29.9, U$29.11, U$29.13, U$29.15, U$30.1, U$30.5, U$30.9, U$30.11, U$30.13, U$30.15
GND15: C61.2, C62.2, C63.2, C64.2, JP16.4, U31.4, U32.2, U$31.1, U$31.5, U$31.9, U$31.11, U$31.13, U$31.15, U$32.1, U$32.5, U$32.9, U$32.11, U$32.13, U$32.15
GND16: C65.2, C66.2, C67.2, C68.2, JP17.4, U33.4, U34.2, U$33.1, U$33.5, U$33.9, U$33.11, U$33.13, U$33.15, U$34.1, U$34.5, U$34.9, U$34.11, U$34.13, U$34.15
GND17: C69.2, C70.2, C71.2, C72.2, JP18.4, U35.4, U36.2, U$35.1, U$35.5, U$35.9, U$35.11, U$35.13, U$35.15, U$36.1, U$36.5, U$36.9, U$36.11, U$36.13, U$36.15
GND18: C73.2, C74.2, C75.2, C76.2, JP19.4, U37.4, U38.2, U$37.1, U$37.5, U$37.9, U$37.11, U$37.13, U$37.15, U$38.1, U$38.5, U$38.9, U$38.11, U$38.13, U$38.15
GND19: C77.2, C78.2, C79.2, C80.2, JP20.4, U39.4, U40.2, U$39.1, U$39.5, U$39.9, U$39.11, U$39.13, U$39.15, U$40.1, U$40.5, U$40.9, U$40.11, U$40.13, U$40.15
GND20: C81.2, C82.2, C83.2, C84.2, JP21.4, U41.4, U42.2, U$41.1, U$41.5, U$41.9, U$41.11, U$41.13, U$41.15, U$42.1, U$42.5, U$42.9, U$42.11, U$42.13, U$42.15
GND21: C85.2, C86.2, C87.2, C88.2, JP22.4, U43.4, U44.2, U$43.1, U$43.5, U$43.9, U$43.11, U$43.13, U$43.15, U$44.1, U$44.5, U$44.9, U$44.11, U$44.13, U$44.15
GND22: C89.2, C90.2, C91.2, C92.2, JP23.4, U45.4, U46.2, U$45.1, U$45.5, U$45.9, U$45.11, U$45.13, U$45.15, U$46.1, U$46.5, U$46.9, U$46.11, U$46.13, U$46.15
GND23: C93.2, C94.2, C95.2, C96.2, JP24.4, U47.4, U48.2, U$47.1, U$47.5, U$47.9, U$47.11, U$47.13, U$47.15, U$48.1, U$48.5, U$48.9, U$48.11, U$48.13, U$48.15
GND24: C97.2, C98.2, C99.2, C100.2, JP25.4, U49.4, U50.2, U$49.1, U$49.5, U$49.9, U$49.11, U$49.13, U$49.15, U$50.1, U$50.5, U$50.9, U$50.11, U$50.13, U$50.15
GND25: C101.2, C102.2, C103.2, C104.2, JP26.4, U51.4, U52.2, U$51.1, U$51.5, U$51.9, U$51.11, U$51.13, U$51.15, U$52.1, U$52.5, U$52.9, U$52.11, U$52.13, U$52.15
GND26: C105.2, C106.2, C107.2, C108.2, JP27.4, U53.4, U54.2, U$53.1, U$53.5, U$53.9, U$53.11, U$53.13, U$53.15, U$54.1, U$54.5, U$54.9, U$54.11, U$54.13, U$54.15
GND27: C109.2, C110.2, C111.2, C112.2, JP28.4, U55.4, U56.2, U$55.1, U$55.5, U$55.9, U$55.11, U$55.13, U$55.15, U$56.1, U$56.5, U$56.9, U$56.11, U$56.13, U$56.15
GND28: C113.2, C114.2, C115.2, C116.2, JP29.4, U57.4, U58.2, U$57.1, U$57.5, U$57.9, U$57.11, U$57.13, U$57.15, U$58.1, U$58.5, U$58.9, U$58.11, U$58.13, U$58.15
GND29: C117.2, C118.2, C119.2, C120.2, JP30.4, U59.4, U60.2, U$59.1, U$59.5, U$59.9, U$59.11, U$59.13, U$59.15, U$60.1, U$60.5, U$60.9, U$60.11, U$60.13, U$60.15
GND30: C121.2, C122.2, C123.2, C124.2, JP31.4, U61.4, U62.2, U$61.1, U$61.5, U$61.9, U$61.11, U$61.13, U$61.15, U$62.1, U$62.5, U$62.9, U$62.11, U$62.13, U$62.15
GND31: C125.2, C126.2, C127.2, C128.2, JP32.4, U63.4, U64.2, U$63.1, U$63.5, U$63.9, U$63.11, U$63.13, U$63.15, U$64.1, U$64.5, U$64.9, U$64.11, U$64.13, U$64.15
GP1: U$1.48, U$4.48
GP2: U$1.42, U$4.42
GP3: U$1.34, U$4.34
GP4: U$1.32, U$4.32
GP5: U$1.30, U$4.30
GP6: U$1.28, U$4.28
GP7: U$1.26, U$4.26
GP8: U$1.25, U$4.25
GP9: U$1.24, U$4.24
GP10: U$5.48, U$6.48
GP11: U$5.42, U$6.42
GP12: U$5.34, U$6.34
GP12_PWM0: U$2.35, U$3.35
GP12_PWM1: U$1.35, U$4.35
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

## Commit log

2014-08-11 initial commit ready for review
    [Edison_Mezzanine_I2C_Breakout.brd, Edison_Mezzanine_I2C_Breakout.sch]
2014-08-12 removed Edzzanine from name
    [Edison_Mezzanine_I2C_Breakout.brd]
2014-09-19 corrected labels, added 3.3v regulator and corrected DCIN pin
    [Edison_Mezzanine_I2C_Breakout.brd, Edison_Mezzanine_I2C_Breakout.sch]
2014-09-23 changed names of files
    [I2C_Breakout_Block.brd, I2C_Breakout_Block.sch]
2014-09-25 repalced I2C resistors
    [I2C_Breakout_Block.brd, I2C_Breakout_Block.sch]
2014-09-25 added bottom pour for VSYS
    [I2C_Breakout_Block.brd]
2014-10-17 Rev to 10, fix gnd/pwr/text
    [I2C_Breakout_Block.brd, I2C_Breakout_Block.sch]
2014-10-17 fixed airwire with Package update
    [I2C_Breakout_Block.brd, I2C_Breakout_Block.sch]
2014-10-17 removed stray Bplace from Package
    [I2C_Breakout_Block.brd, I2C_Breakout_Block.sch]
2014-10-17 Ready for reds Tweak schematic, add value to regulator No known to-do items
    [I2C_Breakout_Block.brd, I2C_Breakout_Block.sch]
2014-10-22 created panels
    [I2C_Breakout_Block-GiantPanel-v10.brd, I2C_Breakout_Block-Panel-v10.brd]
2015-04-01 Updating README and production directory name
    [I2C_Breakout_Block-GiantPanel-v10.brd, I2C_Breakout_Block-Panel-v10.brd]

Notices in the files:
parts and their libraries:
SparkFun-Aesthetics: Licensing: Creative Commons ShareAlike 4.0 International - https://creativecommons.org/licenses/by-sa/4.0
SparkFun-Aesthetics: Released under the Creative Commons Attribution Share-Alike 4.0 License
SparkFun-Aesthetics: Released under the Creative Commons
